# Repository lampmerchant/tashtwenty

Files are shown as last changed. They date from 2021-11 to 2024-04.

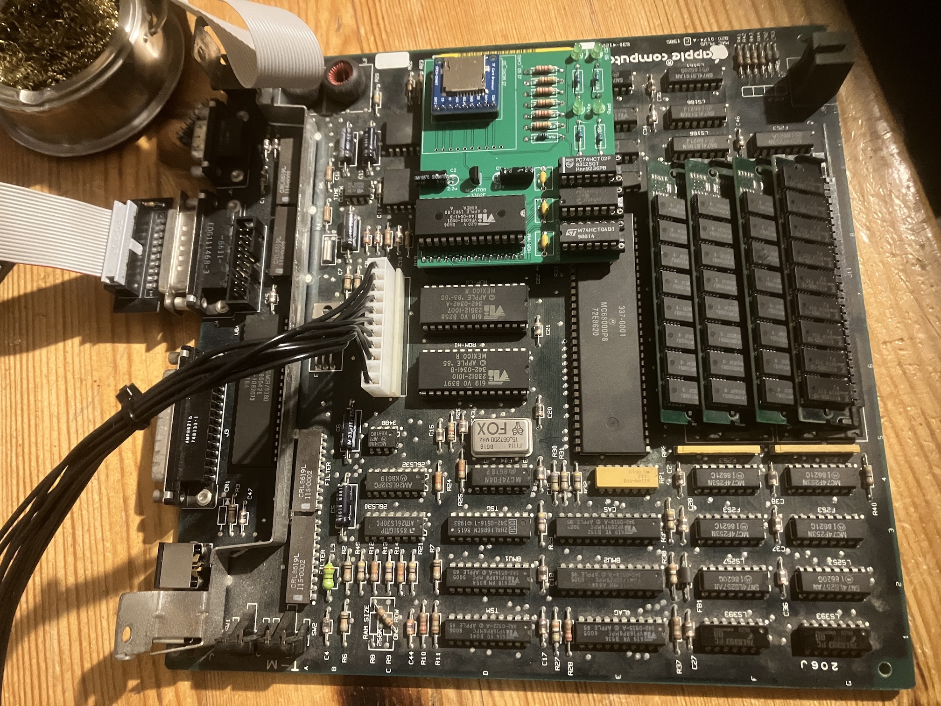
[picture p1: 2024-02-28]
pcb/Internal/what_it_looks_like.jpg

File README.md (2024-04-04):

# TashTwenty

## Elevator Pitch

It's a DCD (the interface used by the Hard Disk 20 to plug in through the disk port) interface, contained entirely within a PIC16F1825 (14 pins, ~$1.84) or PIC16F1704 (14 pins, ~$1.39) microcontroller. It bit-bangs the low-level IWM protocol using the read/write and phase lines on the "DB"-19 disk port, no programmable logic devices of any kind required.

It interfaces to an MMC or compatible card and can emulate up to four DCD devices.  It also has an enable output which can be used to chain more DCD devices (though ROMs only support a maximum of four) and a floppy disk drive.

(Despite the name, there is nothing limiting it to 20 megabytes.)

## Project Status

Functional, though not rigorously tested.

## Caveats

Due to the dearth of documentation on the DCD protocol, the protocol only implements the commands whose formats are known, namely read, write, and device identification.  Responses to other commands are faked.  Fortunately, this seems to be enough for the device to function properly, including formatting.

The disk drive interface relies on use of the phase lines to read and write one-bit registers.  Because the PIC16F1825 firmware mimics the register set in code instead of programmable logic, it has a response time that is, in the worst case, approximately one microsecond.  This may interfere with the ability of faster Macs to detect it, though it is not known to do so at this point.  The PIC16F1704 firmware mimics the register set in logic and responds in effect instantly.

Certain Macs may have a limitation imposed by their ROM on the number of DCDs they support.  See [this link](https://github.com/lampmerchant/tashnotes/blob/main/macintosh/floppy/dcd/dcd.md) for details.

## PCBs and Products

* TashTwenty Tiny by [demik](https://github.com/demik)
   * [Files](https://github.com/lampmerchant/tashtwenty/tree/main/pcb/TashTwenty%20Tiny)
   * See latest release in this repository for gerbers
   * [Buy](https://ko-fi.com/s/2bfee029f5) from [CayMac Vintage](https://ko-fi.com/caymacvintage/shop)
   * Buy [PCBs](https://ko-fi.com/s/01a52bed98), [case panels](https://ko-fi.com/s/50199947e3), and [programmed PICs](https://ko-fi.com/s/2b28fb5562) from [Tashtari](https://ko-fi.com/tashtari/shop)
* TashTwenty Internal by [cheesestraws](https://github.com/cheesestraws)
   * [Files](https://github.com/lampmerchant/tashtwenty/tree/main/pcb/Internal)
   * See latest release in this repository for gerbers
* TashTwenty Rev 3 by [Tashtari](https://github.com/lampmerchant)
   * [Files](https://github.com/lampmerchant/tashtwenty/blob/main/pcb/tashtari-tashtwenty.brd)
   * See latest release in this repository for gerbers
* TashTwenty Budget Version by [CayMac Vintage](https://ko-fi.com/caymacvintage/shop)
   * [Buy](https://ko-fi.com/s/77f53b293e)
* TashTwenty Mega by [warmech](https://68kmla.org/bb/index.php?members/warmech.2497/)
   * Pending release
* TashTwenty Vertical by [hideehoo](https://68kmla.org/bb/index.php?members/hideehoo.4611/)
   * Pending release

## Technical Details

### Building Firmware

Building the firmware requires Microchip MPASM, which is included with their development environment, MPLAB.  Note that you **must** use MPLAB X version 5.35 or earlier or MPLAB 8 as later versions of MPLAB X have removed MPASM.

### MMC Card Format

The MMC card must have an MBR (Master Boot Record) aka DOS-type partition table with up to four primary partitions of type 0xAF (HFS).  Extended partitions are not supported.

#### Custom Icons

In the PIC16F1704 firmware, custom icons are supported using other values besides 0xAF for the partition type byte.  Other partition types besides 0xAF must be the number of a sector (for example, a partition of type 0x01 would point to the second sector) on the card formatted as follows:

* Bytes 0-255 must be the word "ICON" repeated 64 times.
* Bytes 256-383 must be a 32x32 icon, one bit per pixel, with '1' bits denoting black and '0' bits denoting white.
* Bytes 384-511 must be a 32x32 icon mask, one bit per pixel, with '1' bits denoting opaque and '0' bits denoting transparent.

If the sector is not in this format, the partition will be ignored, in order to safely support cards with non-HFS partitions.  Partitions of type 0xAF will always use the built-in icon and the hundred-seventy-sixth sector will not be checked for the format described above.

### DCD (Directly Connected Disks) Protocol

See [this link](https://github.com/lampmerchant/tashnotes/tree/main/macintosh/floppy/dcd) for details.

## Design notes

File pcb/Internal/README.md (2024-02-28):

# Internal

This is cheesey's board for use of TashTwenty internally to a Plus or a 512ke (as far as I know).  It interposes between the IWM and the logic board, and reroutes things so that the back floppy port on the computer still works.

Note that installing this requires the IWM on your Plus/512ke to be socketed!  While building the board is easy, desoldering the IWM from the logic board can be an exercise in applied pain, especially if the solder is crunchy.  Caveat haxor.

To build it, you will need:

* A 74HCT04, a 74HCT02 and a TashTwenty
* A MCP1700-3302E voltage regulator (other 3.3V regulators might do if the pinout is the same)
* An SD card socket.  I used a cheap breakout I got online.  Be aware that the Adafruit micro SD breakout boards have a weird pinout and won't work: the pins on this board are in the same order as they are on the surface mount sockets (and thus on the card themselves), please use one with a boring pinout.
* A handful of capacitors, resistors and LEDs.
* A socket for the IWM and some SIL header rows to 

The PCB is designed to be easy to build.  The component values are marked on the board, I wanted this to feel like a kit to build.  Some notes:

* The SIL headers sticking down from the board go into the leftmost set of DIP holes, the socket on top for the IWM (or the IWM soldered if you're feeling really brave) goes on the right.  Sorry this is unclear on the board; I couldn't work out how to make it clearer.
* Install the SIL headers before the socket or you will hate your life.  Use a DIP socket to hold them in place or you will find that the board won't plug into the DIP socket.
* The LEDs and the resistors next to them (R8-11) are optional.  R1-R7 are *not* optional.
* Do check again that your SD card socket pinout is correct

Notes on installation:

* You may wish to use low-profile IC sockets and low-profile SIL pins if you can: mine only just fits under the metal shielding
* Putting a self-adhesive rubber bumper under the board where it hovers over other chips might well help with keeping everything in place.

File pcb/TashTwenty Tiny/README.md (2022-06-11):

# TashTwenty Tiny

This is a dual PCB design, using mostly through hole components (with the exeption of the SD connector). It's designed this way to be period correct and easy to build for people who don't like soldering SMT components

This folder contains the source KiKad files for the main board. Please check the DB19_IDC20 subfolder for the DB19 to IDC20 adapter. 

## BOM
### BOM (main board)
Here is the BOM for the main board. Part number are what was tested on prototypes board but you may find alternatives easily, especially resistors and sockets

| Reference(s) | Value | Quantity | Notes | Part number |
|---|---|---|---|---|
| C1, C2 | 2.2uF | 2 | radial electrolytic capacitors 4x1.5mm | Jamicon SHR2R2M1HC07M |
| C3, C4 | 100nF | 2 | ceramic capacitor 5.08mm | Weltron 453358 |
| D1 | Green | 1 | 5mm green LED | Kingbright L-53SGD |
| D2 | Yellow+Red | 1 | 5mm dual color common cathode LED | Kingbright L-59EYW |
| J1 | SD Card | 1 | SD Card connector | TE 2041021-1 |
| J2 | IDC20 | 1 | IDC 2x10 Header | BLK 10120560 |
| Q1 | BC337 | 1 | NPN BJT Transistor | BC337 |
| R10, R11 | 330Ω | 2 | standard 0.25W carbon film resistor | TRU TC-CFR0W4J0331 |
| R1, R3, R5, R8 | 1200Ω | 4 | standard 0.25W carbon film resistor | TRU TC-CFR0W4J0122 |
| R2, R4, R6 | 2200Ω | 3 | standard 0.25W carbon film resistor | TRU TC-CFR0W4J0222 |
| R7, R9, R12, R13, R14 | 10kΩ | 5 | standard 0.25W carbon film resistor | TRU TC-CFR0W4J0103 |
| U1 | PIC16F1704 | 1 | PIC 8-bit Microcontroller (DIP-14) | PIC16F1704-I/P |
| U2 | 74ACT08 | 1 | Quad TTL 2-Input AND Gate | SN74ACT08N |
| U3 | 3.3V LDO | 1 | 3.3V LDO voltage regulator | MCP1700-3302E/TO |

Optional

| Reference(s) | Value | Quantity | Notes | Part number |
|---|---|---|---|---|
| J1 | - | 1 | 1x2 header + jumper or wire | - |
| U1, U2 | socket | 2 | DIP-14 socket | TRU 14-LC-TT |
| Case | ABS | 1 | Instrument Case, ABS 2.6x2.6" | HM 1593K(TBU\|GY\|BK) |

Using sockets is recommended because it will allow you to reclaim the gates and microcontroler if your board is broken. This will also allow you to upgrade the firmware if a future firmware is released.

Bridging J3 connects the !ENBL pin on the microcontroller to the !ENBL pin on the 2x20 header, which is what you want for the overwhelming majority of cases where you're connecting the board to an external/secondary floppy drive port that has !ENBL2 in the connector where it should be. It's fine to bridge the two pins with a piece of wire, but if you want this expandability available to you, it'd be better to solder a two-pin header and stick a jumper on it when not in use. The pin closest to the center of the board is the one connected to the microcontroller.

### BOM (adapter board)
This is a matching board for TashTwenty. Please use this one to avoid any damage to your computer or TashTwenty. Others adapters boards are wired differently

| Reference(s) | Value | Quantity | Notes | Part number |
|---|---|---|---|---|
| J1 | IDC20 | 1 | IDC 2x10 Header | BLK 10120560 |
| J2 | DB19 | 1 | DB19 wire male connector | Good luck. |

### BOM (external links)
Here is a mouser link (without the case):
- https://www.mouser.fr/ProjectManager/ProjectDetail.aspx?AccessID=4e3ee30a16

Here us a digikey (without the case):
- https://www.digikey.com/short/n4d8tf04

### IDC cable
You need a cable to connect both boards
Any straight IDC-20 cable should work (pin 1 to pin 1, etc). Macintosh floppy cables are compatible. We used a few Apple cables for prototyping:
- Quadra 800 (Apple P/N 590-0862-B)
- PowerMac 7200-7600 (Apple P/N 590-4529-A)

If you are looking for a new one, a compatible assembly is made buy Advantech under the part number PCL-10120-1E.

## PCBs
the PCBs are simple 2 layers boards. The gerbers are avaible in the release section.
Check for the following files:
* TTT_12.zip: main board revision 1.2
* DB19_IDC20.zip: adapter board revision 1.0

You should be use any mainstream PCB manufacturer for theses. Nothing special about them. PCB thickness should FR-4 with a 1.6mm thickness
On JLCPCB, select "Specify a location" to the option "Remove Order Number"

## Building
Building is straightworfard. It's recommended to start with the SD Card connector, then components, and headers + sockets last.

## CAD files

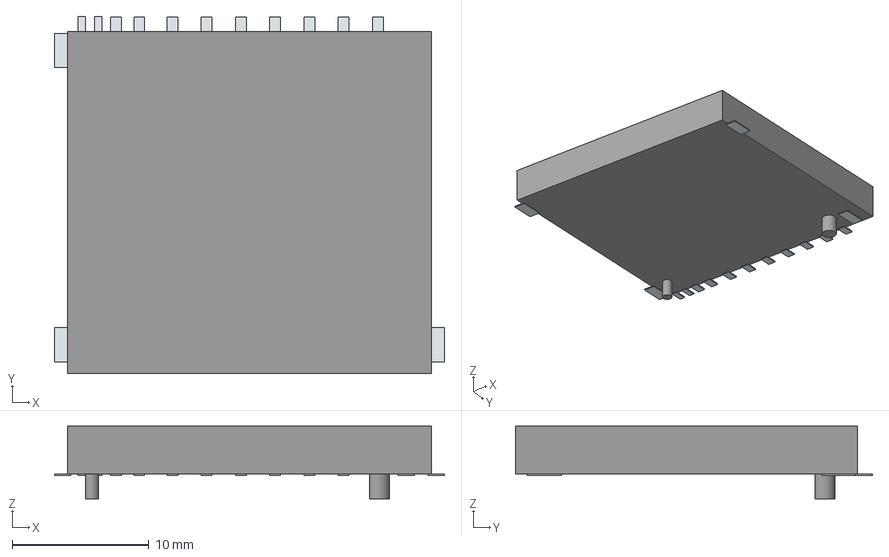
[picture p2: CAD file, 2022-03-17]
pcb/TashTwenty Tiny/2041021-1.stp
28.5 x 26.1 x 5.30 mm
Pins
Lugs x 2

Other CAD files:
pcb/TashTwenty Tiny/2041021-1.stl

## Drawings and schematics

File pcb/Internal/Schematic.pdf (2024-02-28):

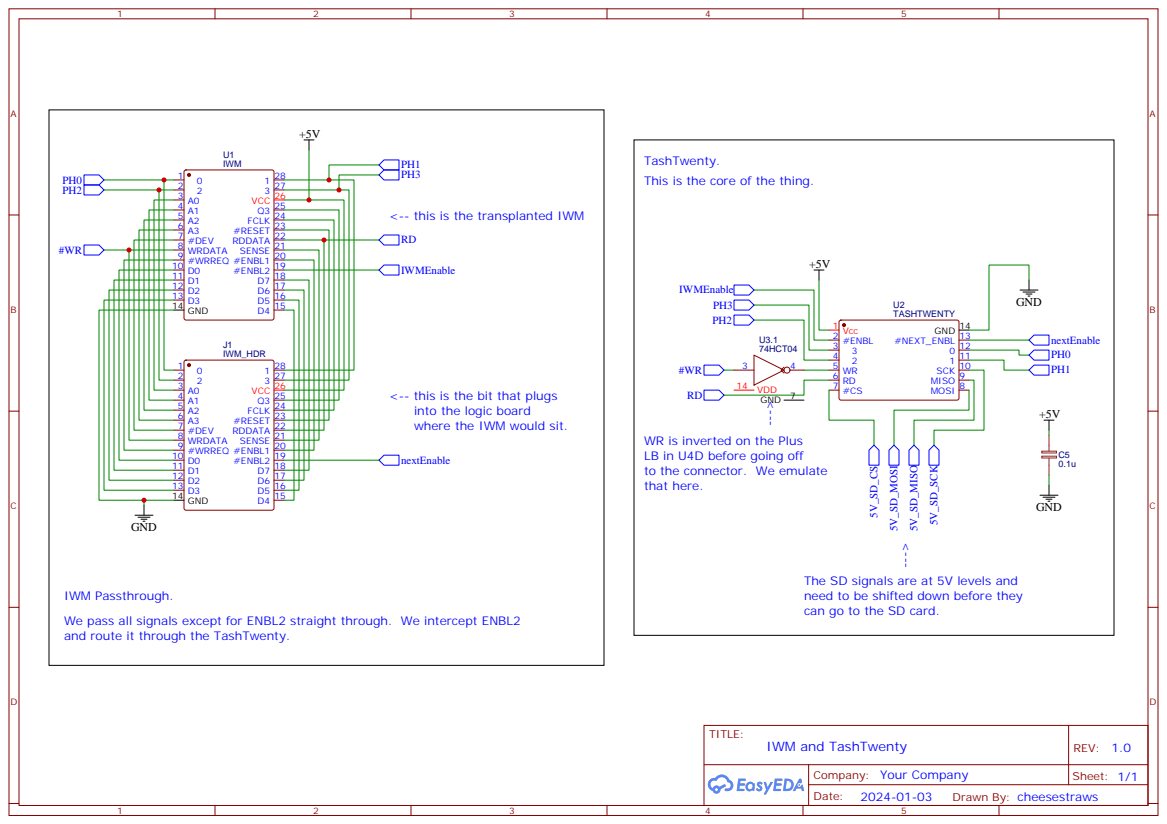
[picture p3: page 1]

TashTwenty.
This is the core of the thing.

<-- this is the transplanted IWM

<-- this is the bit that plugs
into the logic board
where the IWM would sit.

WR is inverted on the Plus
LB in U4D before going off
to the connector. We emulate
that here.

The SD signals are at 5V levels and
need to be shifted down before they
can go to the SD card.

IWM Passthrough.
We pass all signals except for ENBL2 straight through. We intercept ENBL2
and route it through the TashTwenty.

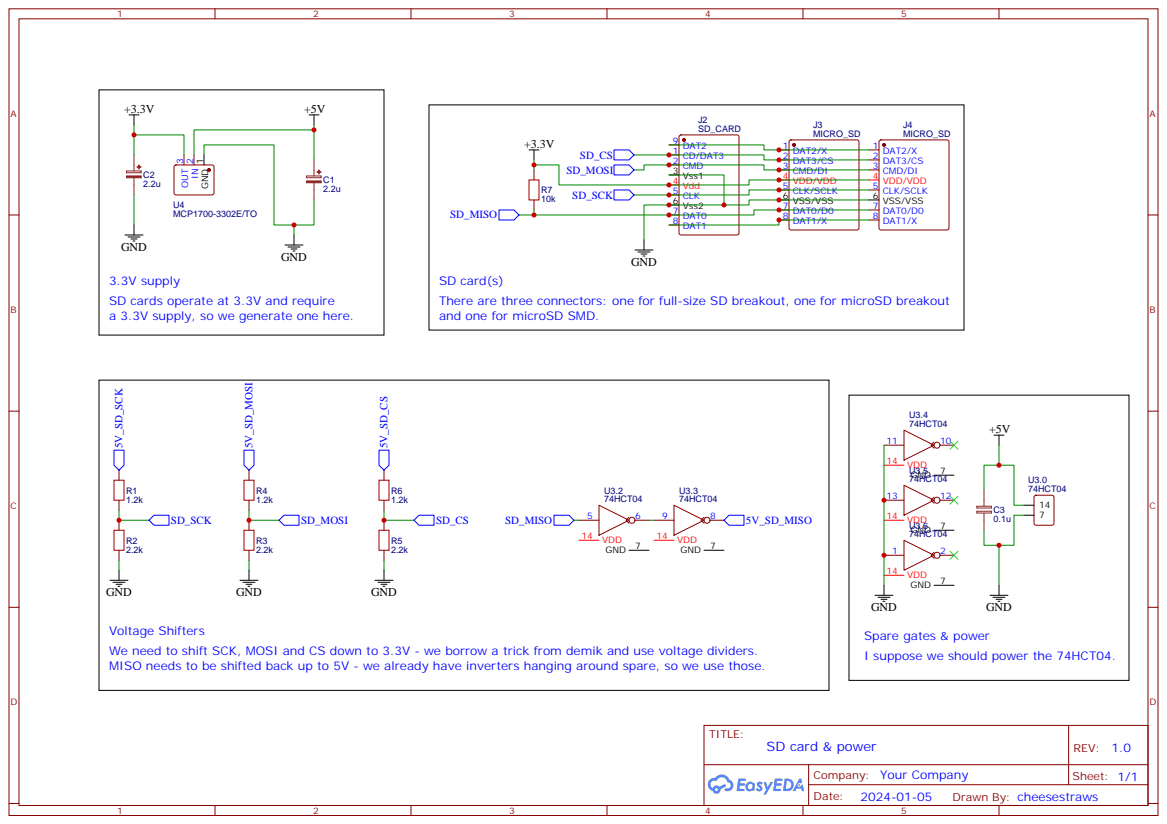
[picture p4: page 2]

3.3V supply
SD cards operate at 3.3V and require
a 3.3V supply, so we generate one here.

SD card(s)
There are three connectors: one for full-size SD breakout, one for microSD breakout
and one for microSD SMD.

Voltage Shifters
We need to shift SCK, MOSI and CS down to 3.3V - we borrow a trick from demik and use voltage dividers.
MISO needs to be shifted back up to 5V - we already have inverters hanging around spare, so we use those.

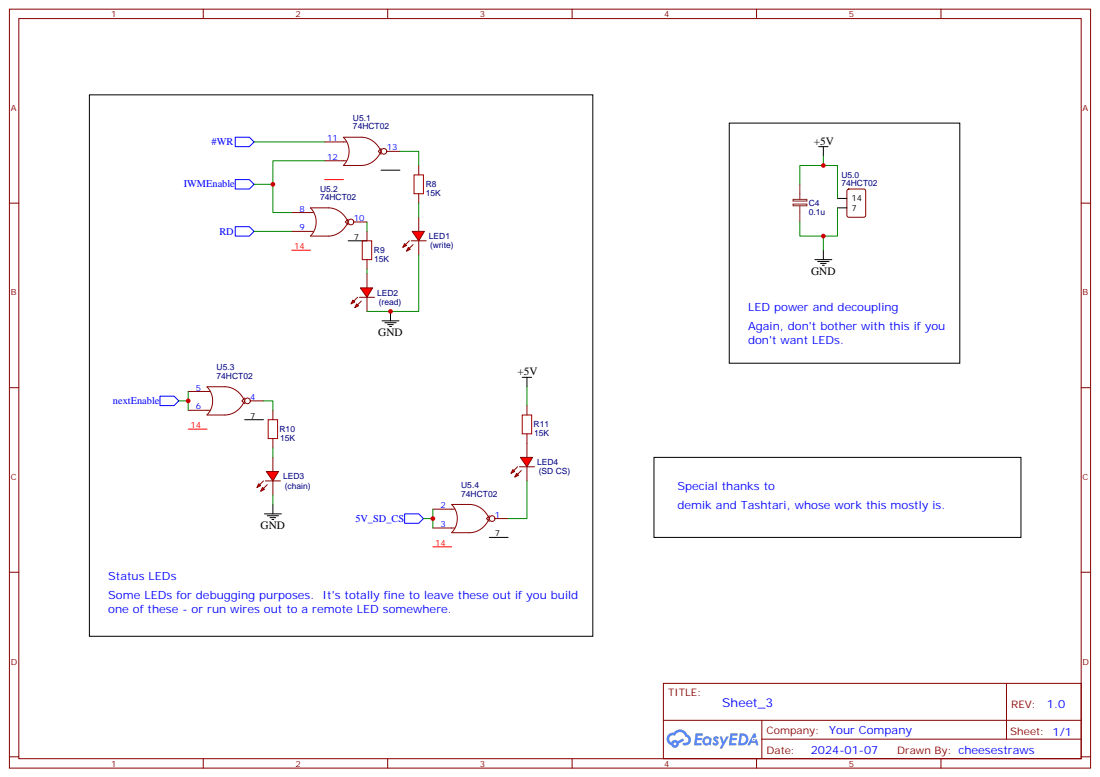
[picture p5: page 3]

LED power and decoupling
Again, don't bother with this if you
don't want LEDs.

Special thanks to
demik and Tashtari, whose work this mostly is.

Status LEDs
Some LEDs for debugging purposes. It's totally fine to leave these out if you build
one of these - or run wires out to a remote LED somewhere.

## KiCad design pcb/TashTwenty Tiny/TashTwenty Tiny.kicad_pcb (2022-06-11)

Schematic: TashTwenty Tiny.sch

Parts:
C3: 100nF; C_Disc_D4.3mm_W1.9mm_P5.00mm
J1: SD_Card; SD_TE_2041021
R1, R3, R5: 1200; R_Axial_DIN0207_L6.3mm_D2.5mm_P7.62mm_Horizontal
R2, R4, R6: 2200; R_Axial_DIN0207_L6.3mm_D2.5mm_P7.62mm_Horizontal
R7, R14: 10k; R_Axial_DIN0207_L6.3mm_D2.5mm_P7.62mm_Horizontal
U1: PIC16F1825-IP; DIP-14_W7.62mm
U2: 74ACT08; DIP-14_W7.62mm

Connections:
+3V3: J1.4, R14.1; also elsewhere on the board
+5V: C3.2, R7.1, U1.1, U2.14; also elsewhere on the board
/MMC_MISO: U1.9, U2.11
/MMC_MISO_LV: J1.7, R14.2, U2.13
/MMC_MOSI: R5.1, U1.8
/MMC_MOSI_LV: J1.2, R5.2, R6.1
/MMC_SCK: R1.1, U1.10
/MMC_SCK_LV: J1.5, R1.2, R2.1
/~MMC_CS: R3.1, U1.7
/~MMC_CS_LV: J1.1, R3.2, R4.1
GND: C3.1, J1.3, J1.6, J1.12, R2.2, R4.2, R6.2, U1.14, U2.7; also elsewhere on the board
unnamed 14: U2.3; also elsewhere on the board
unnamed 17: U2.4, U2.5; also elsewhere on the board
unnamed: R7.2, U2.12
unnamed 20: U2.1, U2.9; also elsewhere on the board
unnamed 21: U2.6; also elsewhere on the board
unnamed 22: U2.8; also elsewhere on the board
PH0: U1.12; also elsewhere on the board
PH1: U1.11; also elsewhere on the board
PH2: U1.4; also elsewhere on the board
PH3: U1.3; also elsewhere on the board
RD: U1.6; also elsewhere on the board
WR: U1.5, U2.10; also elsewhere on the board
~ENABLE: U1.2, U2.2; also elsewhere on the board

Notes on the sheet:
IDC20 Connector
5V to 3.3V level converters
3.3V to 5V level converter
LEDs
PIC1704 is now recommended. PIC1825 still supported.

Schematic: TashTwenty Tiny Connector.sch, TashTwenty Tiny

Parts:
C1, C2: 2.2uF; CP_Radial_D4.0mm_P1.50mm
C4: 100nF; C_Disc_D4.3mm_W1.9mm_P5.00mm
H1, H2, H3: M3; MountingHole_3.2mm_M3_Pad
J2: IDC20; IDC-Header_2x10_P2.54mm_Vertical
J3: Conn_01x02; PinHeader_1x02_P2.54mm_Vertical
U2: 74ACT08; DIP-14_W7.62mm
U3: MCP1700-3302E_TO92; TO-92_Inline

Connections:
+3V3: C1.1, U3.3; also elsewhere on the board
+5V: C2.1, C4.1, J2.11, U2.14, U3.2; also elsewhere on the board
+12V: J2.13, J2.15, J2.17, J2.19; also elsewhere on the board
/MMC_MISO: U2.11; also elsewhere on the board
/MMC_MISO_LV: U2.13; also elsewhere on the board
GND: C1.2, C2.2, C4.2, J2.1, J2.3, J2.5, J2.7, U2.7, U3.1; also elsewhere on the board
unnamed 14: U2.3; also elsewhere on the board
unnamed: J2.14, J3.1
unnamed 17: U2.4, U2.5; also elsewhere on the board
unnamed 19: U2.12; also elsewhere on the board
unnamed 20: U2.1, U2.9; also elsewhere on the board
unnamed 21: U2.6; also elsewhere on the board
unnamed 22: U2.8; also elsewhere on the board
PH0: J2.2; also elsewhere on the board
PH1: J2.4; also elsewhere on the board
PH2: J2.6; also elsewhere on the board
PH3: J2.8; also elsewhere on the board
RD: J2.16; also elsewhere on the board
WR: J2.18, U2.10; also elsewhere on the board
~ENABLE: J3.2, U2.2; also elsewhere on the board

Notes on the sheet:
Mounting holes

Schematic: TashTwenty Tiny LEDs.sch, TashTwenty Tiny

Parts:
D1: LED; LED_D5.0mm_Horizontal_O3.81mm_Z3.0mm
D2: LED_Dual_ACA; LED_D5.0mm-3_Horizontal_O3.81mm_Z3.0mm
Q1: BC337; TO-92_Inline
R8: 1200; R_Axial_DIN0207_L6.3mm_D2.5mm_P7.62mm_Horizontal
R9, R12, R13: 10k; R_Axial_DIN0207_L6.3mm_D2.5mm_P7.62mm_Horizontal
R10, R11: 330; R_Axial_DIN0207_L6.3mm_D2.5mm_P7.62mm_Horizontal
U2: 74ACT08; DIP-14_W7.62mm

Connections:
+5V: R9.1, R13.1, U2.14; also elsewhere on the board
+12V: R8.1; also elsewhere on the board
/MMC_MISO: U2.11; also elsewhere on the board
/MMC_MISO_LV: U2.13; also elsewhere on the board
GND: D1.1, Q1.3, U2.7; also elsewhere on the board
unnamed: D1.2, R8.2
unnamed: D2.1, R11.1
unnamed: D2.2, U2.3
unnamed: D2.3, R10.1
unnamed: Q1.1, R13.2, U2.4, U2.5
unnamed: Q1.2, R12.1
unnamed 19: U2.12; also elsewhere on the board
unnamed: R9.2, U2.1, U2.9
unnamed: R10.2, U2.6
unnamed: R11.2, U2.8
RD: R12.2; also elsewhere on the board
WR: U2.10; also elsewhere on the board
~ENABLE: U2.2; also elsewhere on the board

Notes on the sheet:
This gate will sink the led when /ENABLE is low. Read is /ENABLE low AND RD low Write is /ENABLE low and WR high

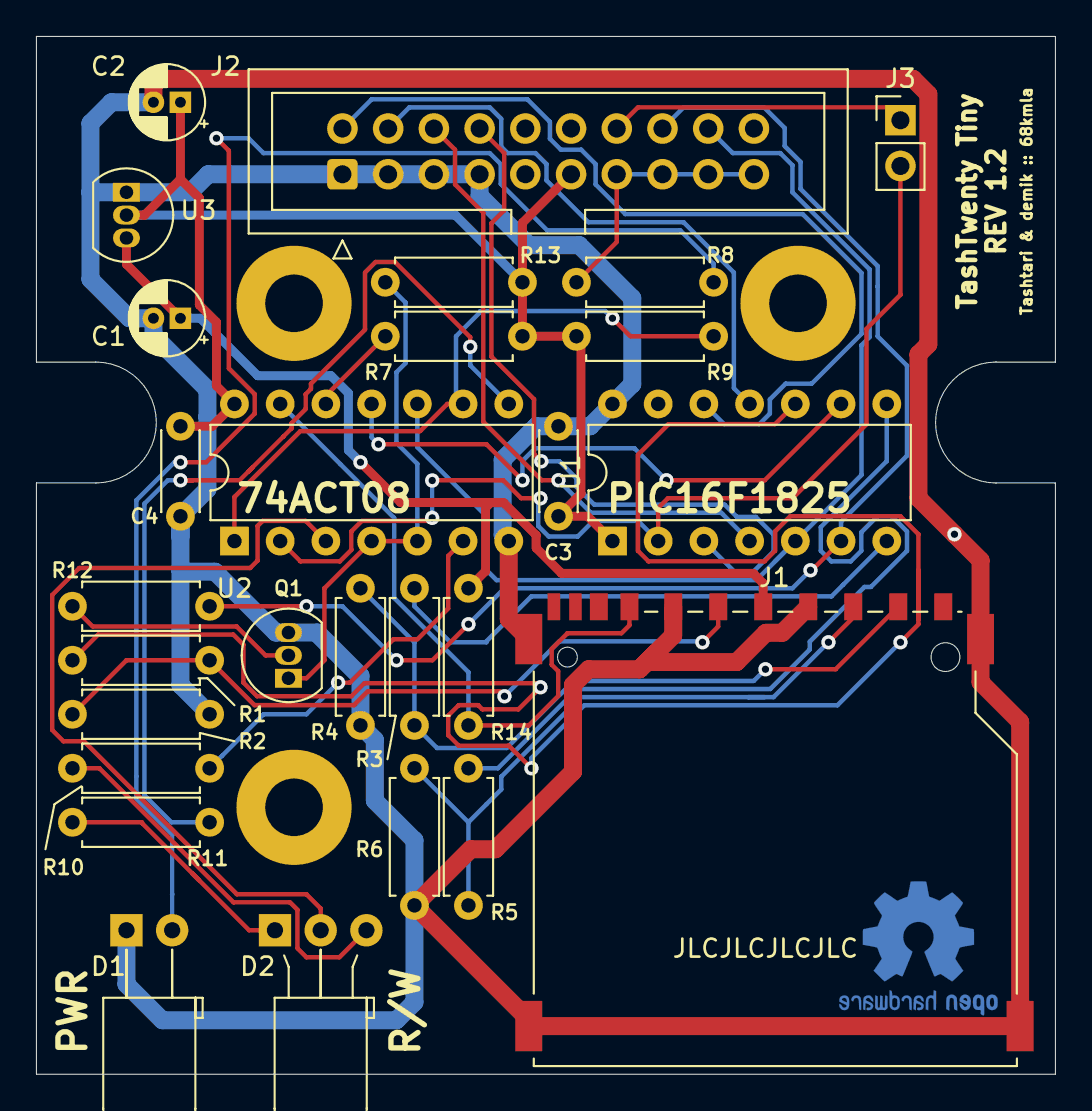
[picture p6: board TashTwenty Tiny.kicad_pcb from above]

Board: 2 copper layers, 56.6 x 57.7 mm, 30 parts (0 on the bottom side), 30 nets.

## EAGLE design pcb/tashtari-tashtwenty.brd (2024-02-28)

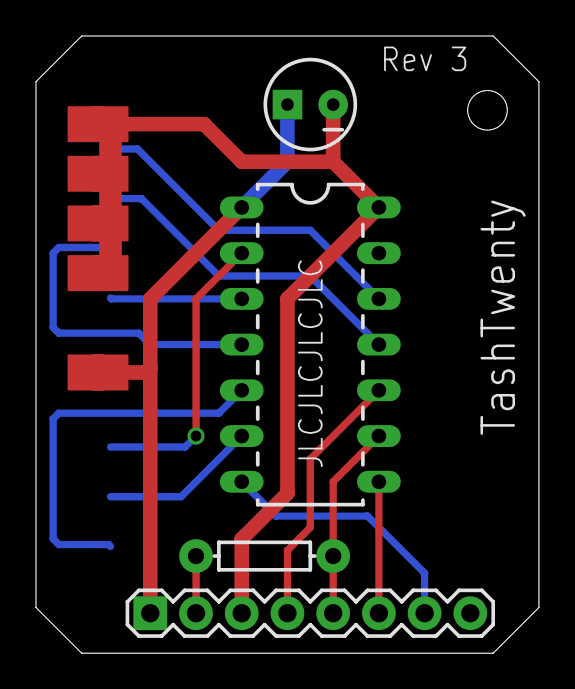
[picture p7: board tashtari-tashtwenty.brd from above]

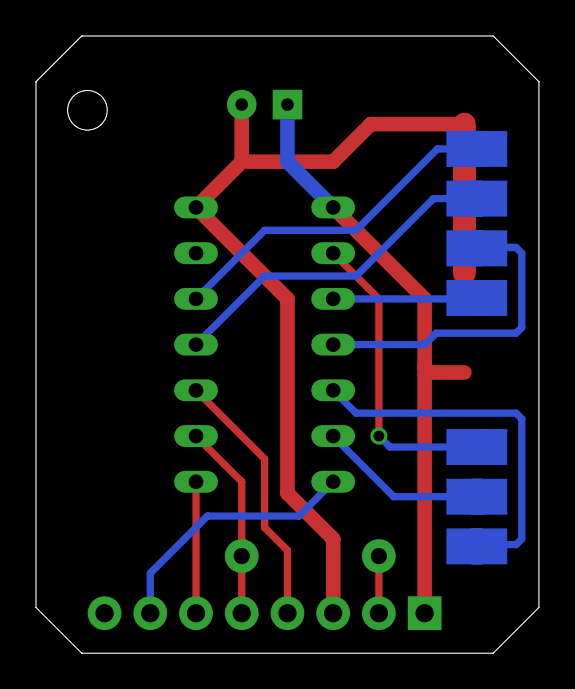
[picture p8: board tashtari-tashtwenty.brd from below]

Board: 2 copper layers, 27.9 x 34.3 mm, 28 parts (14 on the bottom side), 14 nets.

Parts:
E$3, E$4, E$8, E$9, E$10, E$11, E$12, E$13, E$14, E$15, E$18, E$19, E$21, E$22, E$24, E$25, E$27, E$28, E$31, E$32, E$33, E$34, E$35, E$36: TP20SQ
E$37: DIL14
E$38: 1X08
E$39: CPOL-RADIAL-10UF-25V
E$40: AXIAL-0.3

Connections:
S$1: E$14.TP, E$37.1, E$38.1, E$39.1
S$2: E$4.TP, E$9.TP, E$11.TP, E$13.TP, E$37.14, E$38.3, E$39.2
S$3: E$37.7, E$38.7
S$4: E$37.8, E$38.6
S$5: E$37.10, E$38.4
S$6: E$37.9, E$38.5, E$40.P$2
S$7: E$32.TP, E$37.5
S$8: E$34.TP, E$37.6
S$9: E$35.TP, E$37.2
S$10: E$28.TP, E$37.3
S$11: E$25.TP, E$37.4
S$12: E$22.TP, E$37.11
S$13: E$19.TP, E$37.12
S$14: E$38.2, E$40.P$1

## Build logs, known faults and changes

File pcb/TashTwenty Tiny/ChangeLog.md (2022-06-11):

## v1.2
- moved the LEDs a little outward to better fit the new panels

## v1.1
- fixed R2 silkscreen

## v1.0
- Initial public release

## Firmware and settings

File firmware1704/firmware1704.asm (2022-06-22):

;;; 80 characters wide please ;;;;;;;;;;;;;;;;;;;;;;;;;; 8-space tabs please ;;;


;
;;;
;;;;;  TashTwenty: Single-Chip DCD Interface
;;;
;


;;; Connections ;;;

;;;                                                           ;;;
;                         .--------.                            ;
;                 Supply -|01 \/ 14|- Ground                    ;
;      !ENBL --->    RA5 -|02    13|- RA0    ---> Next !ENBL    ;
;        PH3 --->    RA4 -|03    12|- RA1    <--- PH0           ;
;        PH2 --->    RA3 -|04    11|- RA2    <--- PH1           ;
;         WR --->    RC5 -|05    10|- RC0    ---> MMC SCK       ;
;         RD <---    RC4 -|06    09|- RC1    <--- MMC MISO      ;
;    MMC !CS <---    RC3 -|07    08|- RC2    ---> MMC MOSI      ;
;                         '--------'                            ;
;;;                                                           ;;;


;;; Assembler Directives ;;;

	list		P=PIC16F1704, F=INHX32, ST=OFF, MM=OFF, R=DEC, X=ON
	#include	P16F1704.inc
	__config	_CONFIG1, _FOSC_INTOSC & _WDTE_OFF & _PWRTE_ON & _MCLRE_OFF & _CP_OFF & _BOREN_OFF & _CLKOUTEN_OFF & _IESO_OFF & _FCMEN_OFF
			;_FOSC_INTOSC	Internal oscillator, I/O on RA5
			;_WDTE_OFF	Watchdog timer disabled
			;_PWRTE_ON	Keep in reset for 64 ms on start
			;_MCLRE_OFF	RA3/!MCLR is RA3
			;_CP_OFF	Code protection off
			;_BOREN_OFF	Brownout reset off
			;_CLKOUTEN_OFF	CLKOUT disabled, I/O on RA4
			;_IESO_OFF	Internal/External switch not needed
			;_FCMEN_OFF	Fail-safe clock monitor not needed
	__config	_CONFIG2, _WRT_OFF & _PPS1WAY_OFF & _ZCDDIS_ON & _PLLEN_ON & _STVREN_ON & _LVP_OFF
			;_WRT_OFF	Write protection off
			;_PPS1WAY_OFF	PPS can change more than once
			;_ZCDDIS_ON	Zero crossing detector disabled
			;_PLLEN_ON	4x PLL on
			;_STVREN_ON	Stack over/underflow causes reset
			;_LVP_OFF	High-voltage on Vpp to program


;;; Macros ;;;

DELAY	macro	value		;Delay 3*W cycles, set W to 0
	movlw	value
	decfsz	WREG,F
	bra	$-1
	endm

DNOP	macro			;Double-NOP
	bra	$+1
	endm


;;; Constants ;;;

EN_PORT	equ	PORTA
EN_PIN	equ	RA5
NE_PORT	equ	PORTA
NE_PIN	equ	RA0
PH_PORT	equ	PORTA
PH_IOC	equ	IOCAF
PH0_PIN	equ	RA1
PH1_PIN	equ	RA2
PH2_PIN	equ	RA3
PH3_PIN	equ	RA4
WR_PORT	equ	PORTC
WR_IOC	equ	IOCCF
WR_PIN	equ	RC5
CS_PORT	equ	PORTC
CS_PIN	equ	RC3

ERRCODE	equ	0x80	;Code returned in "stat" field when there's an error

;IWMFLAG:
IWMBYTE	equ	7	;Cleared when a byte has been received from IWM
IWMOVER	equ	6	;Set on transition to state 2 or 3 while IWM receiving
IWMTEMP	equ	5	;Used as temporary storage by ISR
IWMCNT1	equ	1	;Counter for how many times the ISR was called
IWMCNT0	equ	0	; "

;M_FLAGS:
M_FAIL	equ	7	;Set when there's been a failure on the MMC interface
M_RDCMD	equ	6	;Set when state machine should do a read command
M_ONGWR	equ	5	;Set when state machine shouldn't stop tran on a write
M_BKADR	equ	4	;Set when block (rather than byte) addressing is in use
M_CDVER	equ	3	;Set when dealing with a V2.0+ card, clear for 1.0


;;; Variable Storage ;;;

	cblock	0x20	;Bank 0 registers
	
	DEVNUM	;Selected device number
	DEVMAX	;Maximum device number
	IWMFLAG	;IWM receiver flags
	IWMFSAP	;IWM post-processing FSA pointer
	IWMLSBS	;LSB shift register for received or transmitted IWM bytes
	IWMREXP	;Size in groups of expected response to command
	CHKSUM	;Checksum
	CMDNUM	;Command number
	CMDCNT	;Command block count
	CMDHIGH	;Command high address byte
	CMDMED	;Command middle address byte
	CMDLOW	;Command low address byte
	RESPERR	;Command response status byte
	
	endc

	cblock	0x70	;Bank-common registers
	
	IWMSR	;Shift register for incoming data from IWM
	M_FLAGS	;MMC flags
	M_CMDN	;The MMC command to be sent, later the R1 response byte	
	M_ADR3	;First (high) byte of the address, first byte of R3/R7 response
	M_ADR2	;Second byte of the address, second byte of R3/R7 response
	M_ADR1	;Third byte of the address, third byte of R3/R7 response
	M_ADR0	;Fourth (low) byte of the address, last byte of R3/R7 response
	M_CRCH	;CRC16 high byte
	M_CRCL	;CRC16 low byte
	M_STATE	;State of card state machine
	X5	;Various purposes
	X4	;Various purposes
	X3	;Various purposes
	X2	;Various purposes
	X1	;Various purposes
	X0	;Various purposes
	
	endc


;;; Vectors ;;;

	org	0x0		;Reset vector
	movlp	high Init
	goto	Init

	org	0x4		;Interrupt vector
	;fall through


;;; Interrupt Handler ;;;

Interrupt
	btfsc	INTCON,INTF	;If we're here because of a rising edge on
	bra	IntDisable	; !ENBL, go take care of that
	lslf	IWMSR,W		;Make space for three new bits in the IWM shift
	lslf	WREG,W		; register
	lslf	WREG,W		; "
	movlb	30		;Grab the bits off the two-bit shift register
	iorwf	CLCDATA,W	; and put them into the IWM shift register (we
	movwf	IWMSR		; know the LSB of CLCDATA will be low because
	movlb	0		; !HSHK is low whenever we're receiving)
	incf	IWMFLAG,F	;Increment the counter of times the interrupt
	btfss	IWMFLAG,1	; handler was called; if this is the first of
	bra	IntFirst	; two, skip ahead
	movlb	7		;Clear any triggered edge on WR so we can spin
	bcf	WR_IOC,WR_PIN	; and wait for one later
	movlb	0		; "
	btfsc	WR_PORT,WR_PIN	;Grab the current state of WR and put that into
	bsf	IWMSR,0		; bit 0 of the IWM shift register
	btfss	INTCON,IOCIF	;Spin until we get an edge on WR or a rising
	bra	$-1		; edge on PH1 (a transition to state 2 or 3)
	nop			;Delay
	clrf	IWMFLAG		;Signal we have a byte and reset call counter
	movlw	high LutInv|0x80;Point to inversion LUT for translation ahead
	movwf	FSR0H		; "
	btfsc	WR_PORT,WR_PIN	;Grab the current state of WR (first bit of a
	bsf	IWMFLAG,IWMTEMP	; new cell) and put that into our temp bit
	clrf	TMR2		;Re-calibrate Timer2
	movf	IWMSR,W		;Use the inversion LUT to change the high/low
	movwf	FSR0L		; levels into transitions or non-transitions
	movf	INDF0,W		; and turn it into an IWM byte and write that
	movwf	INDF1		; to the IWM queue
	btfss	PH_PORT,PH0_PIN	;If PH0 is clear, clear the MSB of the byte we
	bcf	INDF1,7		; just write to indicate a suspend is on
	clrf	IWMSR		;Clear the IWM shift register and put the first
	btfsc	IWMFLAG,IWMTEMP	; bit of the new cell that we saved in the temp
	bsf	IWMSR,1		; bit into bit 1 of it
	movlw	-33		;Set Timer0 to interrupt again after 33 cycles
	movwf	TMR0		; and clear its interrupt flag
	bcf	INTCON,TMR0IF	; "
	DNOP			;Delay to get the read at a better position
	btfsc	WR_PORT,WR_PIN	;Grab the current state of WR and put that into
	bsf	IWMSR,0		; bit 0 of the IWM shift register
	movlb	7		;If we were released from the loop by a
	btfsc	PH_IOC,PH1_PIN	; transition to state 2 or 3, we're done
	bra	IntDataOver	; receiving data and must set flags accordingly
	movlb	0		;Otherwise, post process this byte
	bra	IntPostProc	; "

IntFirst
	btfsc	WR_PORT,WR_PIN	;Grab the current state of WR and put that into
	bsf	IWMSR,0		; bit 0 of the IWM shift register
	movlw	-27		;Set Timer0 to interrupt again after 27 cycles
	movwf	TMR0		; "
	bcf	INTCON,TMR0IF	;Clear Timer0 interrupt flag
	retfie
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

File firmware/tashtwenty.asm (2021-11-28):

;;; 80 characters wide please ;;;;;;;;;;;;;;;;;;;;;;;;;; 8-space tabs please ;;;


;
;;;
;;;;;  TashTwenty: Single-Chip DCD Interface
;;;
;


;;; License ;;;

;    This program is free software: you can redistribute it and/or modify
;    it under the terms of the GNU General Public License as published by
;    the Free Software Foundation, either version 3 of the License, or
;    (at your option) any later version.
;
;    This program is distributed in the hope that it will be useful,
;    but WITHOUT ANY WARRANTY; without even the implied warranty of
;    MERCHANTABILITY or FITNESS FOR A PARTICULAR PURPOSE.  See the
;    GNU General Public License for more details.
;
;    You should have received a copy of the GNU General Public License
;    along with this program.  If not, see <https://www.gnu.org/licenses/>.


;;; Connections ;;;

;;;                                                           ;;;
;                         .--------.                            ;
;                 Supply -|01 \/ 14|- Ground                    ;
;      !ENBL --->    RA5 -|02    13|- RA0    ---> Next !ENBL    ;
;        PH3 --->    RA4 -|03    12|- RA1    <--- PH0           ;
;        PH2 --->    RA3 -|04    11|- RA2    <--- PH1           ;
;         WR --->    RC5 -|05    10|- RC0    ---> MMC SCK       ;
;         RD <---    RC4 -|06    09|- RC1    <--- MMC MISO      ;
;    MMC !CS <---    RC3 -|07    08|- RC2    ---> MMC MOSI      ;
;                         '--------'                            ;
;;;                                                           ;;;


;;; Assembler Directives ;;;

	list		P=PIC16F1825, F=INHX32, ST=OFF, MM=OFF, R=DEC, X=ON
	#include	P16F1825.inc
	__config	_CONFIG1, _FOSC_INTOSC & _WDTE_OFF & _PWRTE_ON & _MCLRE_OFF & _CP_OFF & _CPD_OFF & _BOREN_OFF & _CLKOUTEN_OFF & _IESO_OFF & _FCMEN_OFF
			;_FOSC_INTOSC	Internal oscillator, I/O on RA5
			;_WDTE_OFF	Watchdog timer disabled
			;_PWRTE_ON	Keep in reset for 64 ms on start
			;_MCLRE_OFF	RA3/!MCLR is RA3
			;_CP_OFF	Code protection off
			;_CPD_OFF	Data memory protection off
			;_BOREN_OFF	Brownout reset off
			;_CLKOUTEN_OFF	CLKOUT disabled, I/O on RA4
			;_IESO_OFF	Internal/External switch not needed
			;_FCMEN_OFF	Fail-safe clock monitor not needed
	__config	_CONFIG2, _WRT_OFF & _PLLEN_ON & _STVREN_ON & _LVP_OFF
			;_WRT_OFF	Write protection off
			;_PLLEN_ON	4x PLL on
			;_STVREN_ON	Stack over/underflow causes reset
			;_LVP_OFF	High-voltage on Vpp to program


;;; Macros ;;;

DELAY	macro	value		;Delay 3*W cycles, set W to 0
	movlw	value
	decfsz	WREG,F
	bra	$-1
	endm

DNOP	macro
	bra	$+1
	endm


;;; Constants ;;;

;FLAGS:
ABORTED	equ	7	;Set if a transmit or receive operation was aborted
RNFERR	equ	6	;Set if host tries to access a too-high block address
DEVSEL1	equ	1	;MSB of which device is selected
DEVSEL0	equ	0	;LSB of which device is selected

;M_FLAGS:
M_FAIL	equ	7	;Set when there's been a failure on the MMC interface
M_CMDLR	equ	6	;Set when R3 or R7 is expected (5 bytes), not R1
M_CMDRB	equ	5	;Set when an R1b is expected (busy signal after reply)
M_MBRD	equ	4	;Set when a multiblock read is in progress
M_MBWR	equ	3	;Set when a multiblock write is in progress
M_BKADR	equ	2	;Set when block (rather than byte) addressing is in use
M_CDVER	equ	1	;Set when dealing with a V2.0+ card, clear for 1.0

;DVxFLAG:
DV_EXST	equ	7	;Set when device exists

;Firmware version
FWVER_3	equ	0x20
FWVER_2	equ	0x21
FWVER_1	equ	0x11
FWVER_0	equ	0x28


;;; Variable Storage ;;;

	cblock	0x70	;Bank-common registers
	
	FLAGS	;You've got to have flags
	GROUPS	;Count of groups to transmit, count of groups received
	CRC16H	;High byte of the CRC16 register
	CRC16L	;Low byte of the CRC16 register
	M_FLAGS	;MMC flags
	M_CMDN	;The MMC command to be sent, later the R1 response byte	
	M_ADR3	;First (high) byte of the address, first byte of R3/R7 response
	M_ADR2	;Second byte of the address, second byte of R3/R7 response
	M_ADR1	;Third byte of the address, third byte of R3/R7 response
	M_ADR0	;Fourth (low) byte of the address, last byte of R3/R7 response
	TEMP	;Various purposes
	TEMP2	;Various purposes
	D3
	D2
	D1
	D0
	
	endc

	cblock	0x20	;Bank 0 registers
	
	;Partition struct
	DV0FLAG	;Device 0 flags
	DV0LN_2	;Device 0 LBA length
	DV0LN_1	; "
	DV0LN_0	; "
	DV0ST_3	;Device 0 start LBA
	DV0ST_2	; "
	DV0ST_1	; "
	DV0ST_0	; "
	DV1FLAG	;Device 1 flags
	DV1LN_2	;Device 1 LBA length
	DV1LN_1	; "
	DV1LN_0	; "
	DV1ST_3	;Device 1 start LBA
	DV1ST_2	; "
	DV1ST_1	; "
	DV1ST_0	; "
	DV2FLAG	;Device 2 flags
	DV2LN_2	;Device 2 LBA length
	DV2LN_1	; "
	DV2LN_0	; "
	DV2ST_3	;Device 2 start LBA
	DV2ST_2	; "
	DV2ST_1	; "
	DV2ST_0	; "
	DV3FLAG	;Device 3 flags
	DV3LN_2	;Device 3 LBA length
	DV3LN_1	; "
	DV3LN_0	; "
	DV3ST_3	;Device 3 start LBA
	DV3ST_2	; "
	DV3ST_1	; "
	DV3ST_0	; "
	
	;Error (high nibble) and unknown command (low nibble) log
	LOG_00
	LOG_01
	LOG_02
	LOG_03
	LOG_04
	LOG_05
	LOG_06
	LOG_07
	LOG_08
	LOG_09
	LOG_0A
	LOG_0B
	LOG_0C
	LOG_0D
	LOG_0E
	LOG_0F
	LOG_10
	LOG_11
	LOG_12
	LOG_13
	LOG_14
	LOG_15
	LOG_16
	LOG_17
	LOG_18
	LOG_19
	LOG_1A
	LOG_1B
	LOG_1C
	LOG_1D
	LOG_1E
	LOG_1F
	
	;Card info
	CARDINF

	;TODO Unused 7 bytes
	UNUSED6
	UNUSED5
	UNUSED4
	UNUSED3
	UNUSED2
	UNUSED1
	UNUSED0
	
	endc

	cblock	0x68	;Top of data buffer (receive shorthand)
	
	RC_SYNC	;Sync byte
	RC_CMDG	;Command groups + 0x80
	RC_RSPG	;Response groups + 0x80
	RC_CMDN	;Command number
	RC_BLKS	;Block count
	RC_ADRH	;Block address high
	RC_ADRM	;Block address middle
	RC_ADRL	;Block address low
	
	endc

	cblock	0x68	;Top of data buffer (transmit shorthand)
	
	TX_CMDN	;Command number
	TX_BLKS	;Block count
	TX_STAT	;Status
	TX_PAD1	;Pad byte
	TX_PAD2	;Pad byte
	TX_PAD3	;Pad byte
	TX_CSUM	;Checksum, if reply is only one group long
	
	endc


;;; Vectors ;;;

	org	0x0		;Reset vector
	bra	Init

	org	0x4		;Interrupt vector


;;; Interrupt Handler ;;;

;BSR must always be at 0 when interrupts are on

Interrupt
	lslf	PORTA,W		;32 entries in the jump table, each has four
	brw			; instructions; jump to the one matching state
	nop			;We expect RA0 to be high
	nop			; "
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

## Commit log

2021-11-26 add board rev 1
    [tashtari.brd]
2022-03-17 initial relase of the TashTwentt Tiny PCB: a dual PCB THT implementation of TashTwenty
    [2041021-1.stl, 2041021-1.stp, TashTwenty Tiny Connector.sch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]
2022-03-18 added TTT adapter board
    [DB19_IDC20.kicad_pcb, DB19_IDC20.sch]
2022-03-18 added small readme and BOM
2022-03-20 added GitHub, 68kmla URLs and revisions to source files
    [DB19_IDC20.kicad_pcb, DB19_IDC20.sch, TashTwenty Tiny Connector.sch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]
2022-03-21 added info about BOMs, mouser basket, etc…
2022-03-21 added info for IDC-20 cable
2022-05-10 added PCB Front Panel
    [TTT_FP.kicad_pcb, TTT_FP.sch]
2022-05-10 added Ribbon Cable P/N
2022-05-17 added back panel PCB
    [TTT_BP.sch]
2022-05-20 added missing TTT_BP.kicad_pcb
    [TTT_BP.kicad_pcb]
2022-05-21 PCB board rev 1.1: fixed R2 silkscreen
    [TashTwenty Tiny.kicad_pcb, TashTwenty Tiny.sch]
2022-06-06 Switched PIC P/N to PIC16F1704
2022-06-06 PCB board rev 1.2: fix LED positions
    [TashTwenty Tiny.kicad_pcb, TashTwenty Tiny.sch]
2022-06-07 Rev 1.1 Front Panel: align LED and SD holes
    [TTT_FP.kicad_pcb, TTT_FP.sch]
2024-02-28 remove gerbers (they go in release)
2024-02-28 add list of PCBs/products to README
    [tashtari-tashtwenty.brd]

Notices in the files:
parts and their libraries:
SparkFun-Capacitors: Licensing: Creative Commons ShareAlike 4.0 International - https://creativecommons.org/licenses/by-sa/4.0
